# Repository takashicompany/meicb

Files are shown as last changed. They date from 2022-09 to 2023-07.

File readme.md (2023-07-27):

# MeiCB

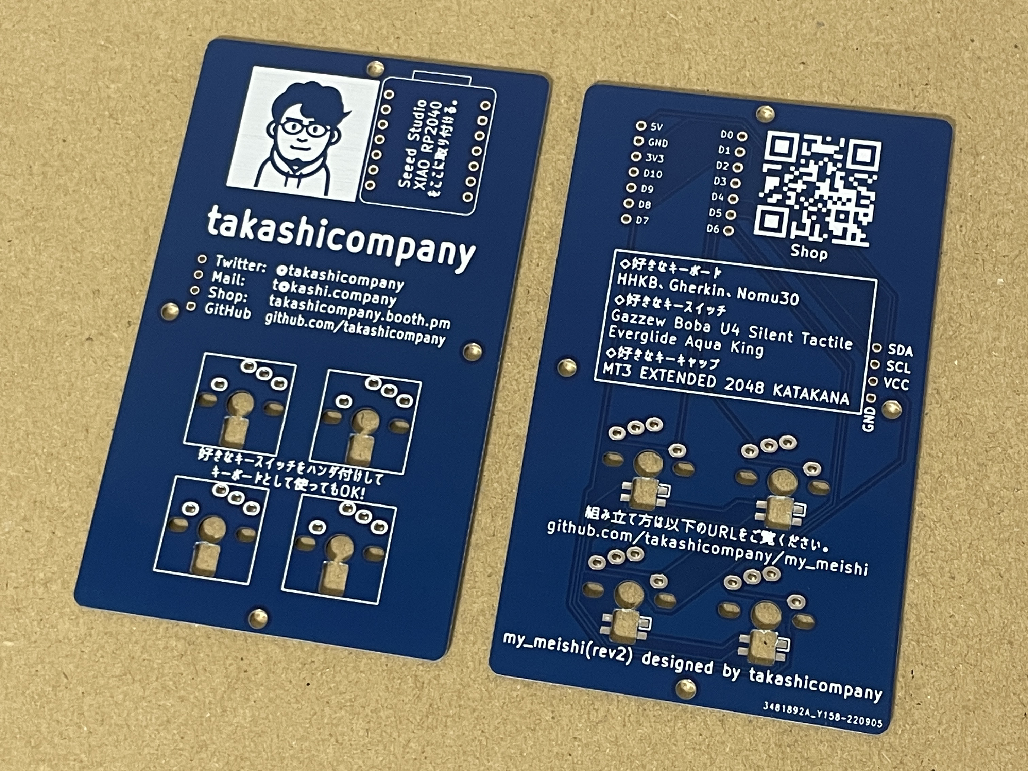
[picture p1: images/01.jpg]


MeiCB(メイシービー)は名刺サイズのキーボード基板です。  
名刺として使えますし、キースイッチやMCUを搭載することで簡易的なマクロパッドとしても利用できます。  
Kicadデーターを公開予定ですので、ご自身のプロフィールやアイコン画像を載せたMeiCBをつくることも可能です。  

(my_meishiから名前を変更しました。)

## 機能の対応状況

### Rev2(my_meishi)

一部の機能は、まだファームウェアの調査中だったり、基板側に拡張が必要なケースがあります。

|機能|対応|詳細|
|:--|:--|:--|
|OLED|？|現在調査中。|
|LED|✗|基板側で追加の実装が必要になる想定。|
|VIA|？|現在調査中。|

## 組み立てに必要な部品

|部品名|個数|備考|
|:--|:--|:--|
|[XIAO RP2040](https://akizukidenshi.com/catalog/g/gM-17044/)|1||
|キースイッチ|4個|取り付けは[Cherry MX互換キースイッチ](https://shop.yushakobo.jp/collections/all-switches/cherry-mx-%E4%BA%92%E6%8F%9B-%E3%82%B9%E3%82%A4%E3%83%83%E3%83%81)と[Kailh Choc v1互換キースイッチ](https://shop.yushakobo.jp/collections/all-switches/kailh-choc-v1%E3%82%B9%E3%82%A4%E3%83%83%E3%83%81)に対応|
|キーキャップ|4個||
|[ゴム足シール](https://shop.yushakobo.jp/collections/all-keyboard-parts/products/a0800ur-01-6)|4個||

## 組み立て方

### 1. 基板の表側にXIAO RP2040を取り付ける

基板の表側右上の箇所にXIAO RP2040を取り付けます。  
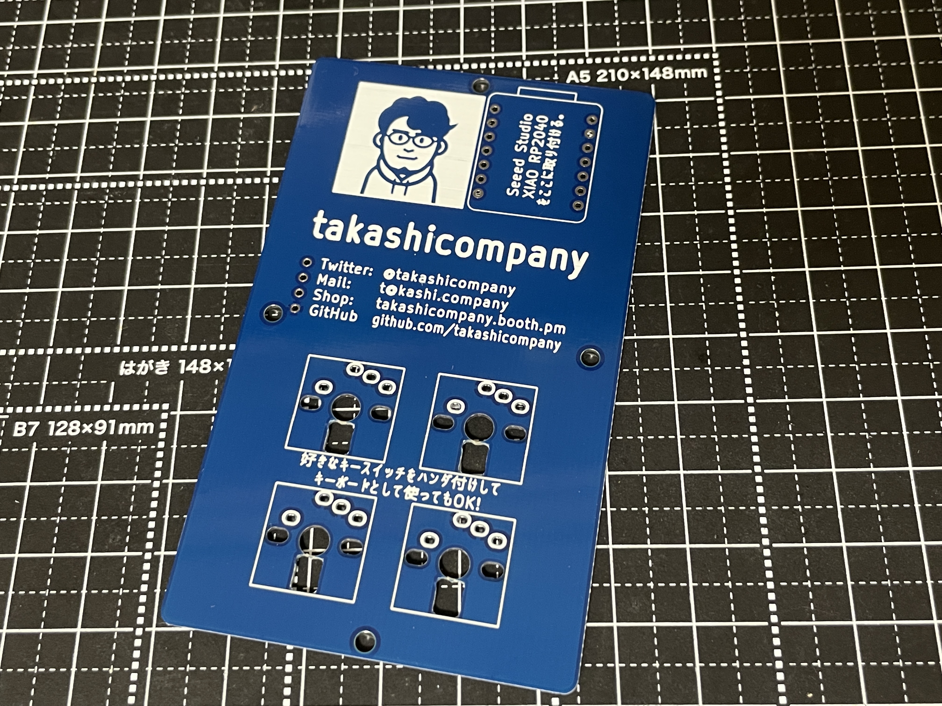
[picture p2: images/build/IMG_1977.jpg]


XIAO RP2040とピンをはんだ付けします。  
ピンの足がXIAO RP2040の平らな面側に来るようにピンを差しハンダ付けを行います。  
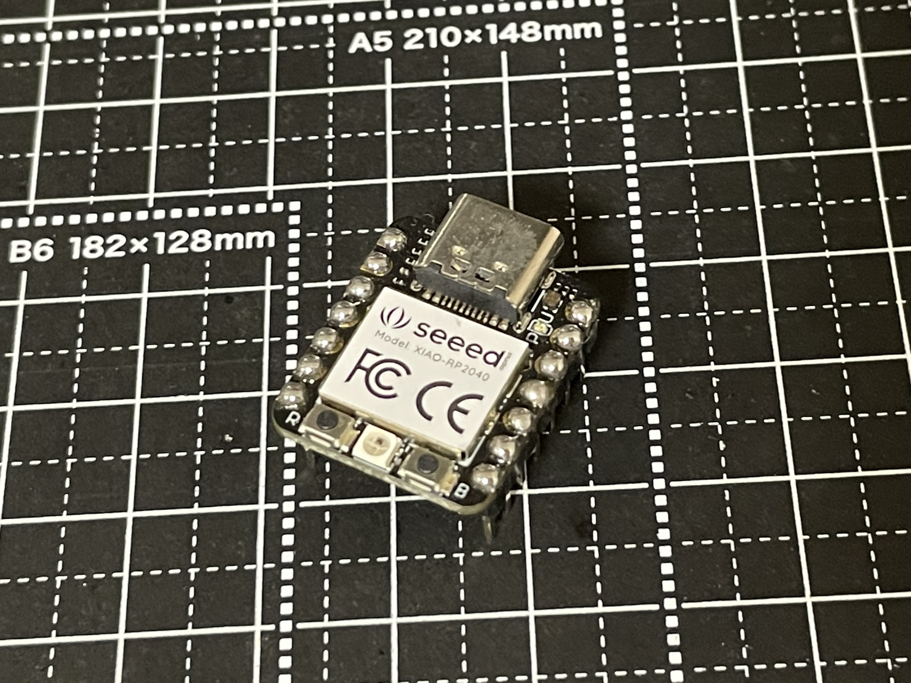
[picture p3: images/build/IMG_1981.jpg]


XIAO RP2040をMeiCB基板に差します。  
USBの口が外側を向くようにしてください。  
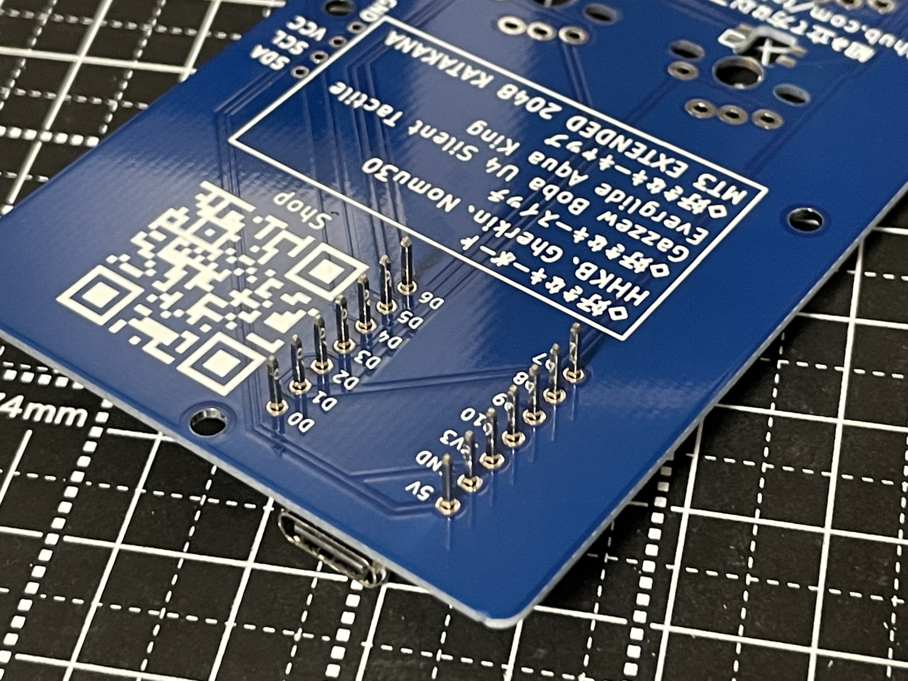
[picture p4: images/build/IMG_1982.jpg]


表面から見たときに、このようになっていれば問題ありません。  
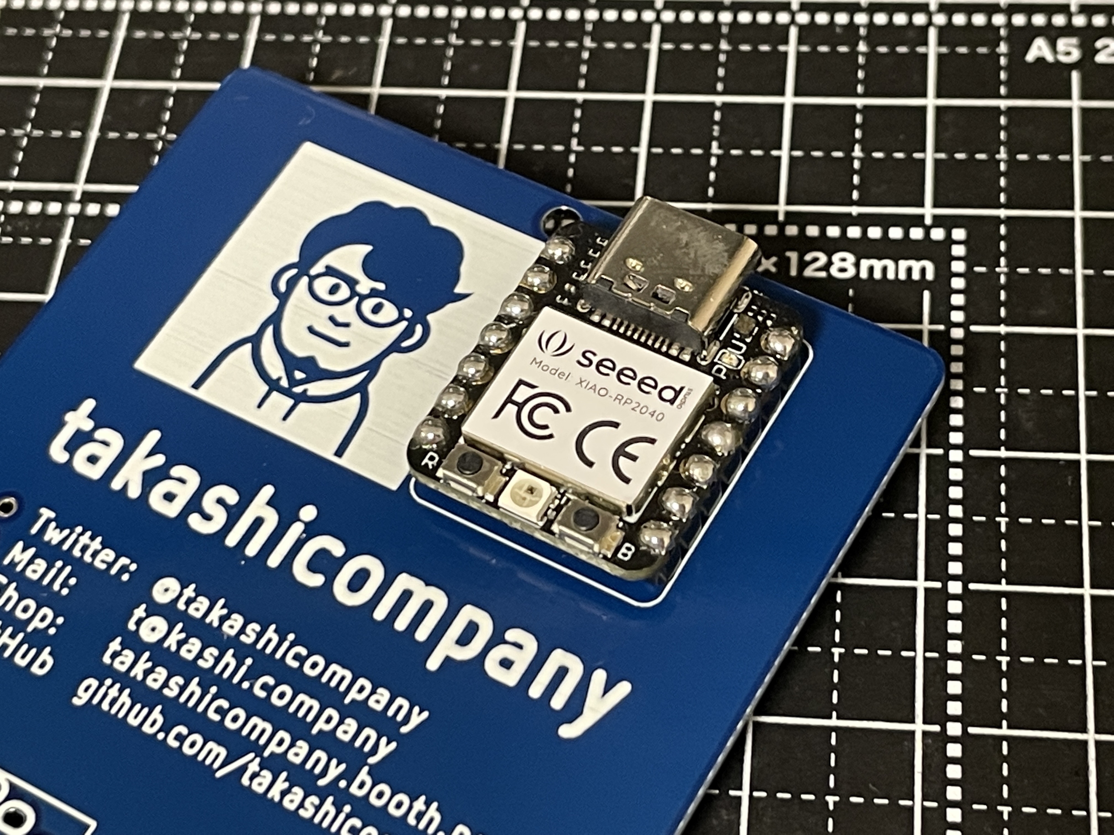
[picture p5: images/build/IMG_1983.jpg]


基板とピンをハンダ付けする前にピンをニッパーなどで短く切っておくとハンダ付けがしやすくなり且つ仕上がりが綺麗になります。  
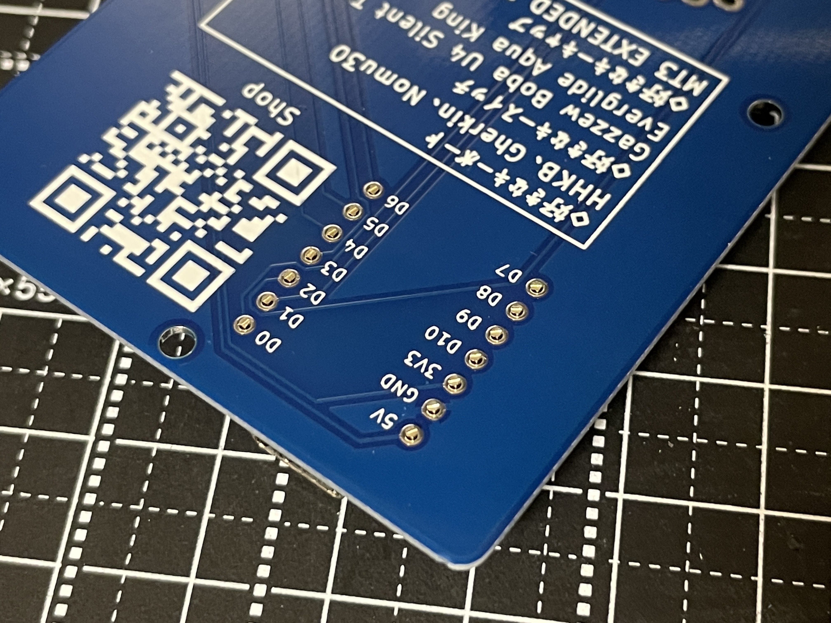
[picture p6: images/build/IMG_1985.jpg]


全てのピンをハンダ付けしたら完了です。  
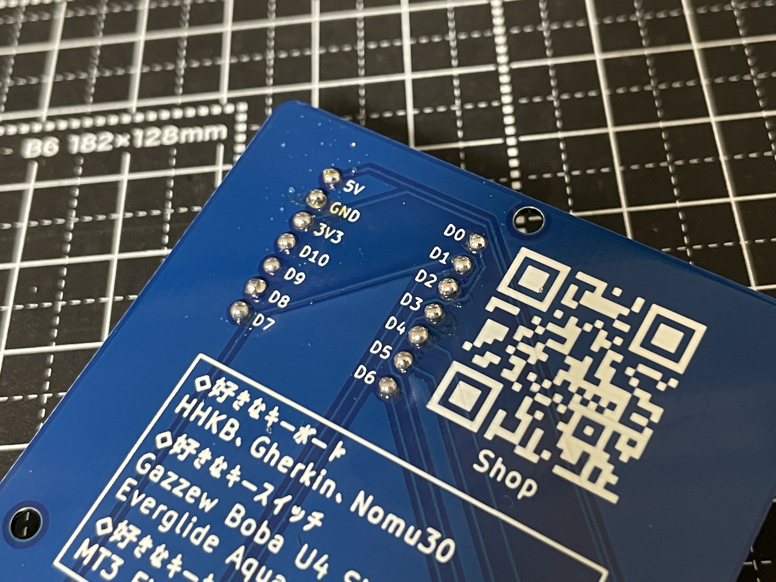
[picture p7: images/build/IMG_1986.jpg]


### 2. キースイッチを取り付ける

キースイッチを取り付けます。  
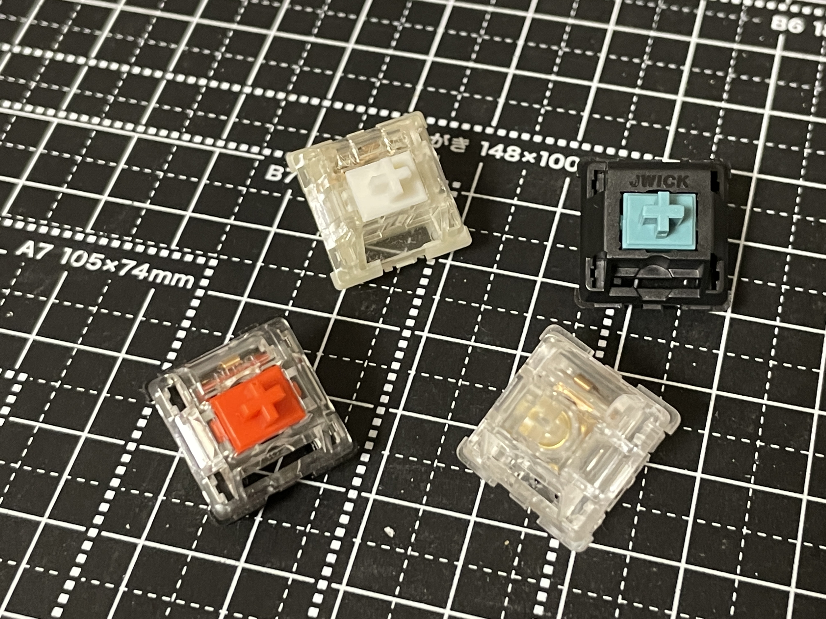
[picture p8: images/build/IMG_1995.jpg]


キースイッチをMeiCB基板に配置します。  
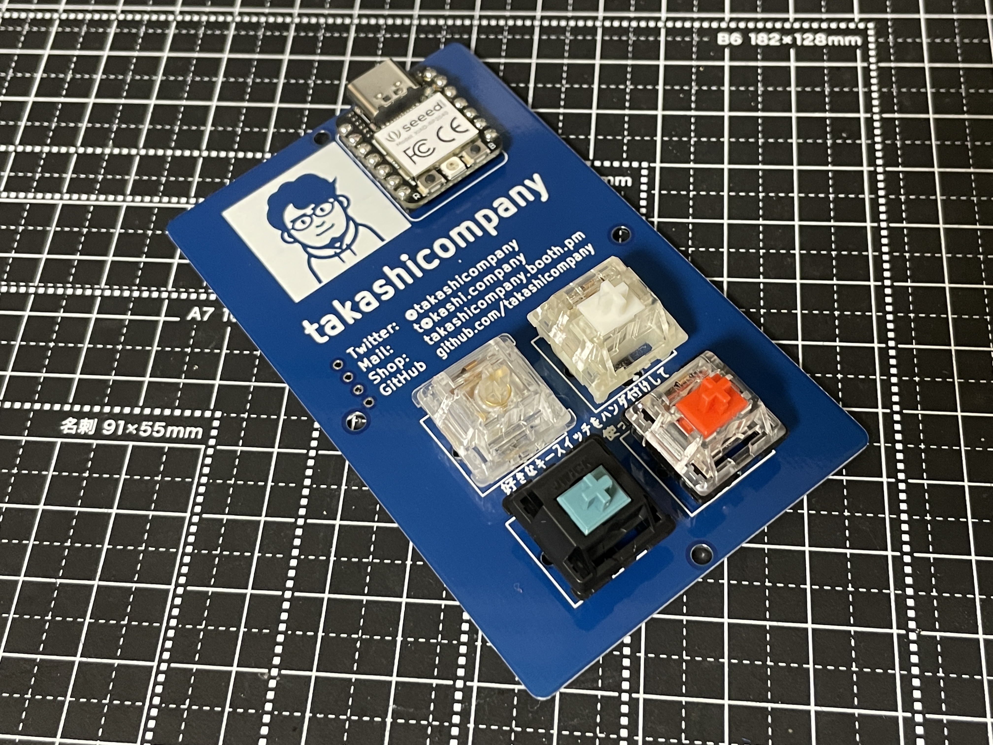
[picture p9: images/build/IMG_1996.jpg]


キースイッチをマスキングテープなどで固定すると、以降の作業をスムーズに進められます。  
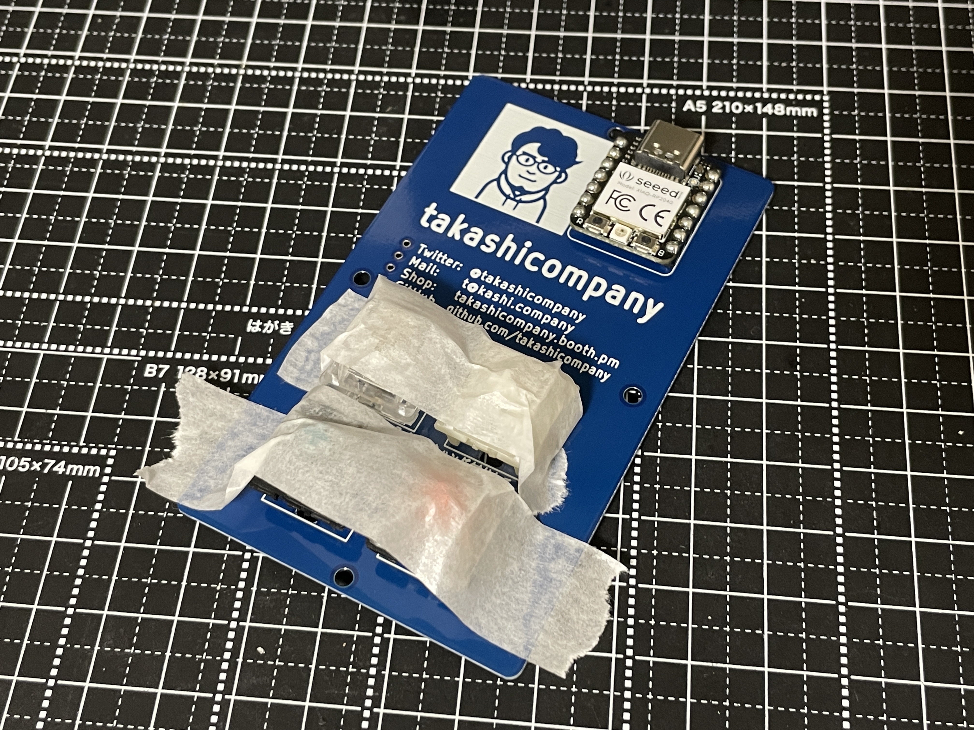
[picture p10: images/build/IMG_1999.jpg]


MeiCB基板を裏返したときに、キースイッチの足が出ていることを確認します。  
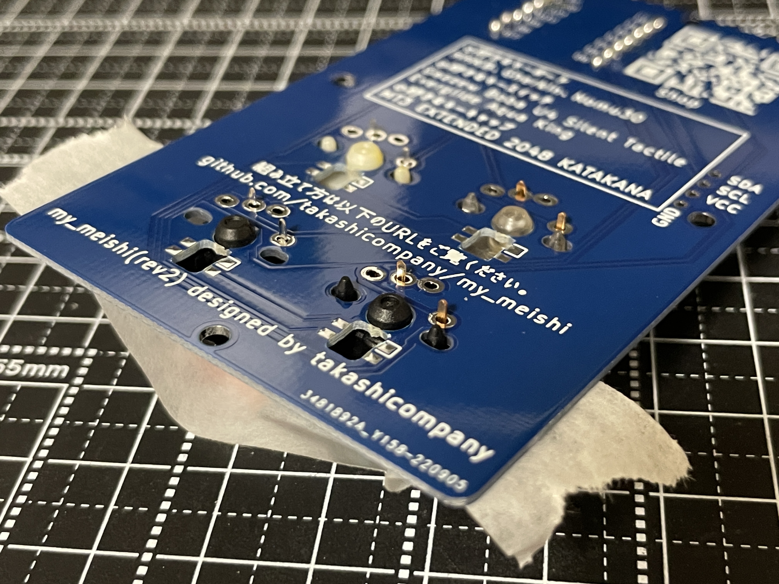
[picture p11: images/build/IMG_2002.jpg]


MeiCB基板とキースイッチをハンダ付けします。  
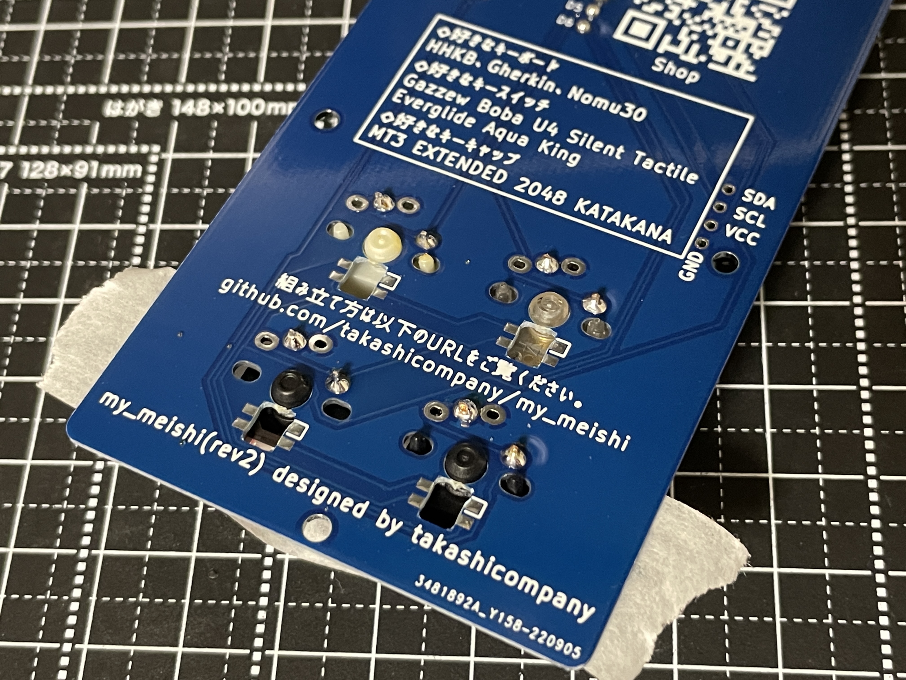
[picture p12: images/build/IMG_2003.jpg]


キーキャップを取り付けます。  
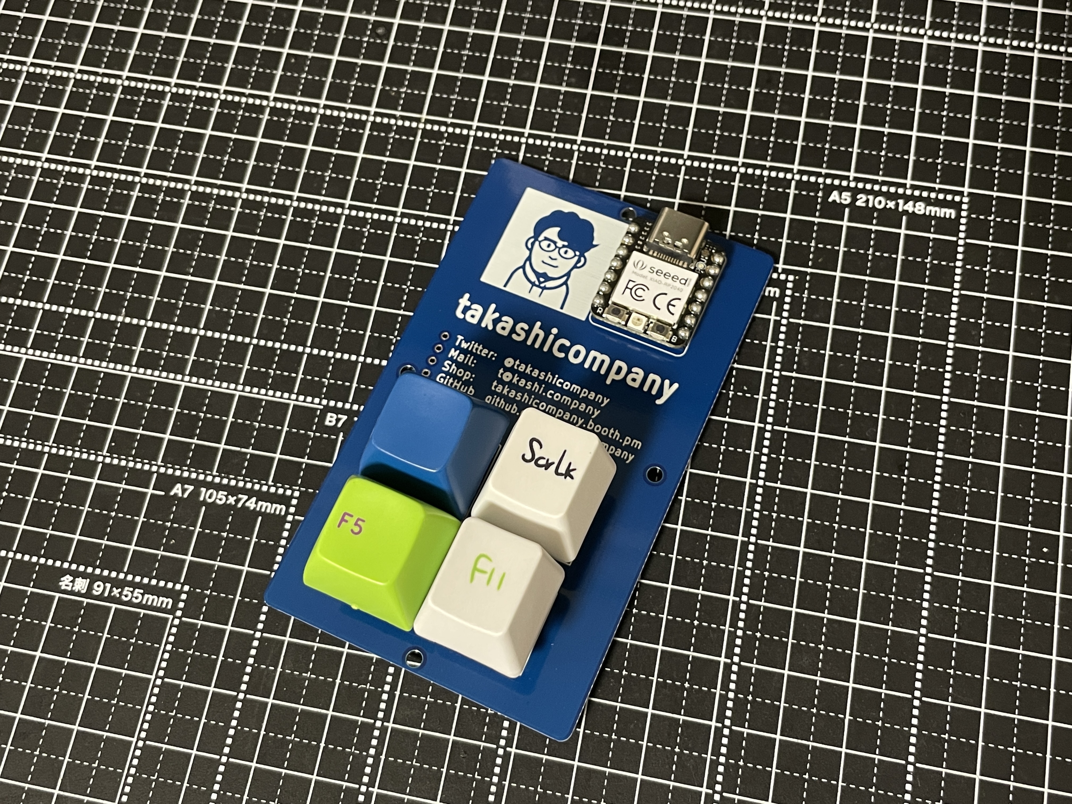
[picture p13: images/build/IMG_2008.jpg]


### 3. ファームウェアの書き込み

XIAO RP2040上のUSB口の反対側にある、Bと書かれたボタンを押しながらUSBを繋ぐとファームウェア書き込み状態にできます。

ファームウェアは[こちら](https://github.com/takashicompany/meicb/tree/master/firmware)にございます。

RPI-RP2と書かれたドライブに.uf2をドロップすると、書き込まれます。

ソースコードは[こちら](https://github.com/takashicompany/qmk_firmware/tree/meicb/v1/keyboards/takashicompany/meicb)です。



Remap等への対応は後日予定しております。

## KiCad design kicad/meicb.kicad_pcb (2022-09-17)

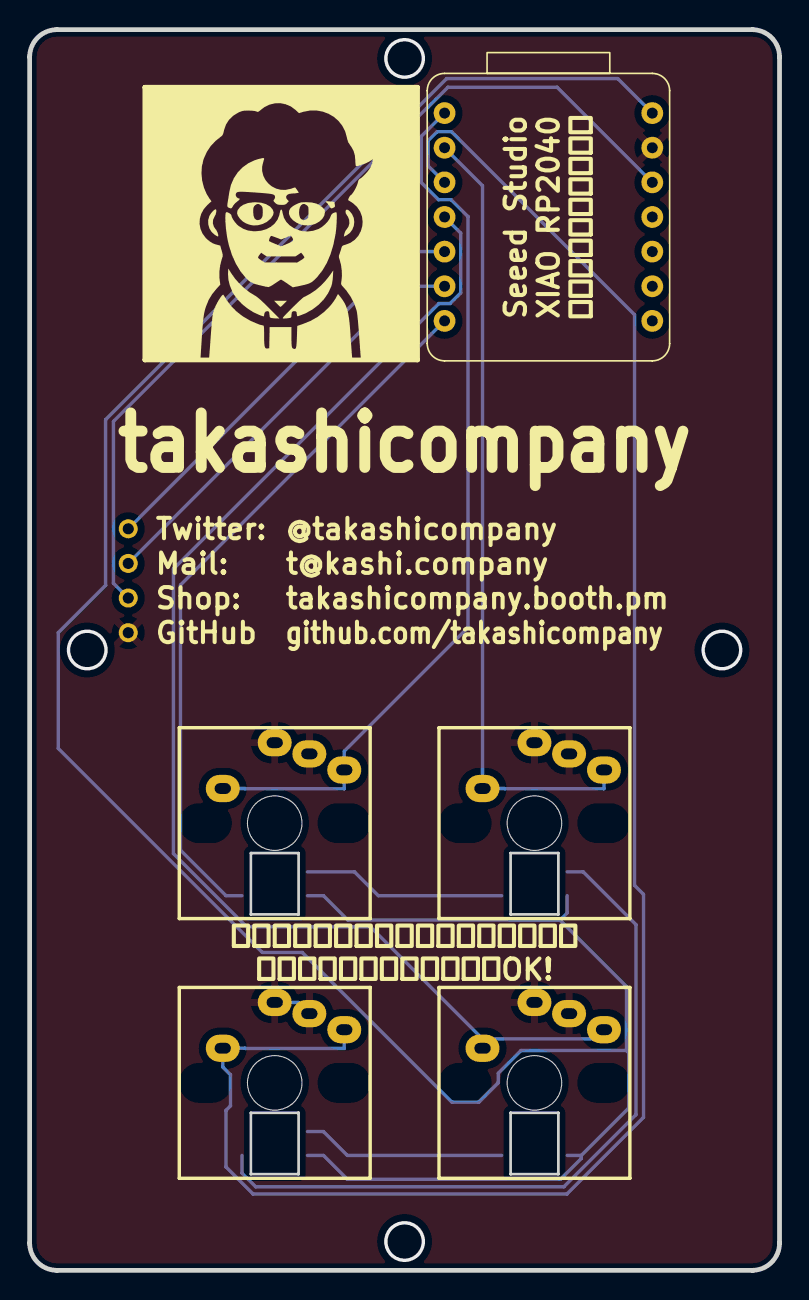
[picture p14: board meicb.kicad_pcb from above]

Board: 2 copper layers, 55.0 x 91.0 mm, 11 parts (0 on the bottom side), 13 nets.

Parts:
Icon: LOGO; icon
LED1, LED2, LED3, LED4: SK6812MINI-E; SK6812MINI_bg
M1: XIAO-RP2040; XIAO-RP2040-inside-only
OL1: OLED; OLED_v2
SW1, SW2, SW3, SW4: SW_Push; CherryMX-MidHeight-Choc_TH_Biased

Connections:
+3V3: M1.12 (3V3), OL1.3 (VCC)
+5V: LED1.1 (VDD), LED2.1 (VDD), LED3.1 (VDD), LED4.1 (VDD), M1.14 (5V)
GND: LED1.3 (VSS), LED2.3 (VSS), LED3.3 (VSS), LED4.3 (VSS), M1.13 (GND), OL1.4 (GND), SW1.2, SW2.2, SW3.2, SW4.2
unnamed: LED1.2 (DOUT), LED2.4 (DIN)
unnamed: LED2.2 (DOUT), LED3.4 (DIN)
unnamed: LED3.2 (DOUT), LED4.4 (DIN)
SCL: M1.6 (D5), OL1.2 (SCL)
SDA: M1.5 (D4), OL1.1 (SDA)
SW1_IN: M1.1 (D0), SW1.1
SW2_IN: M1.2 (D1), SW2.1
SW3_IN: M1.3 (D2), SW3.1
SW4_IN: M1.4 (D3), SW4.1
led: LED1.4 (DIN), M1.7 (D6)

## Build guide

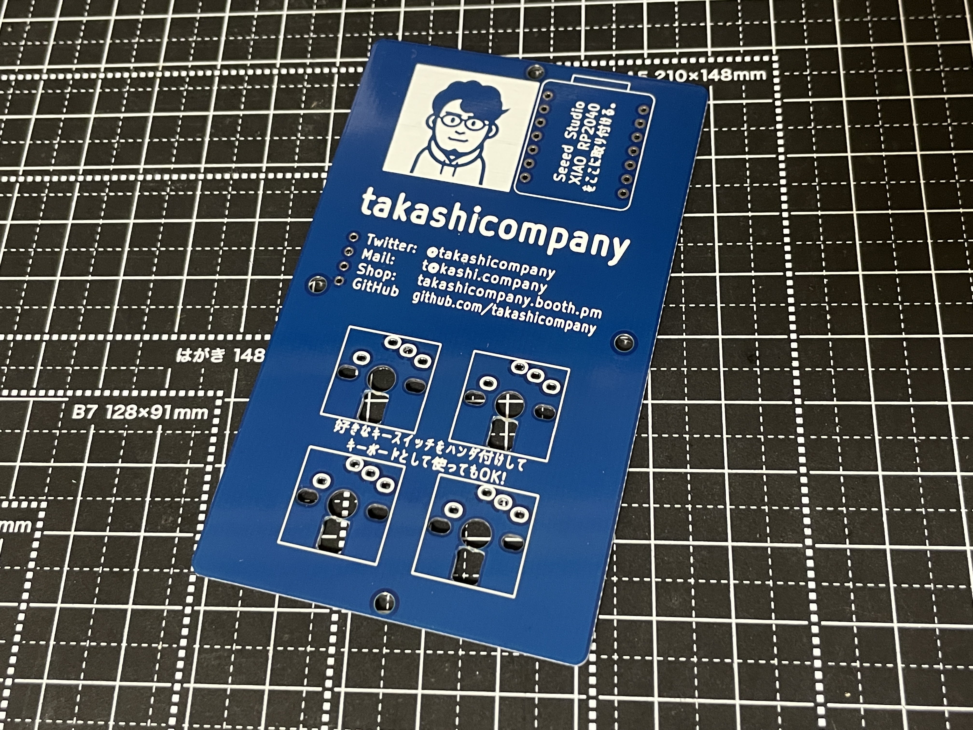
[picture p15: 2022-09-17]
images/build/IMG_1976.jpg

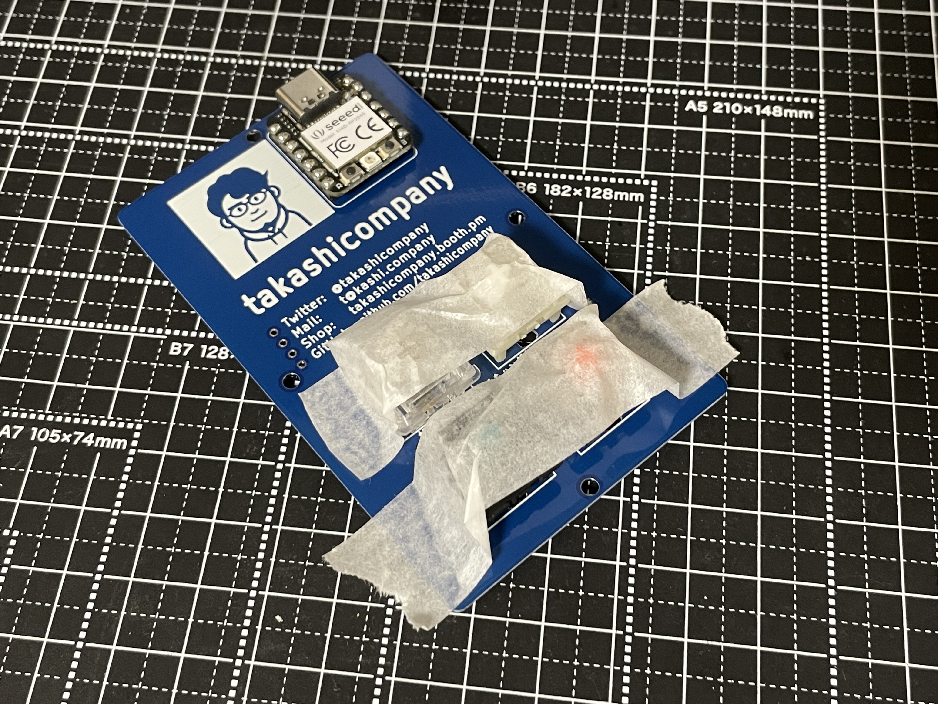
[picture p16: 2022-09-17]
images/build/IMG_1997.jpg

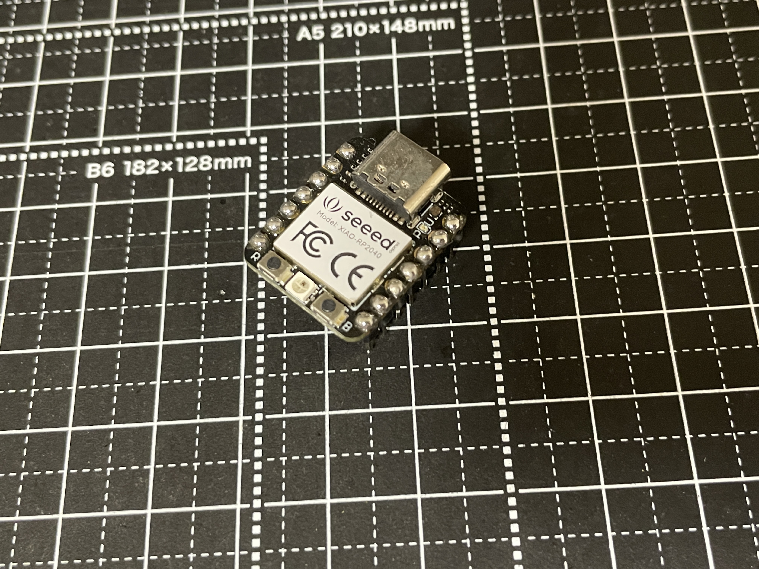
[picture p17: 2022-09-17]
images/build/IMG_1978.jpg

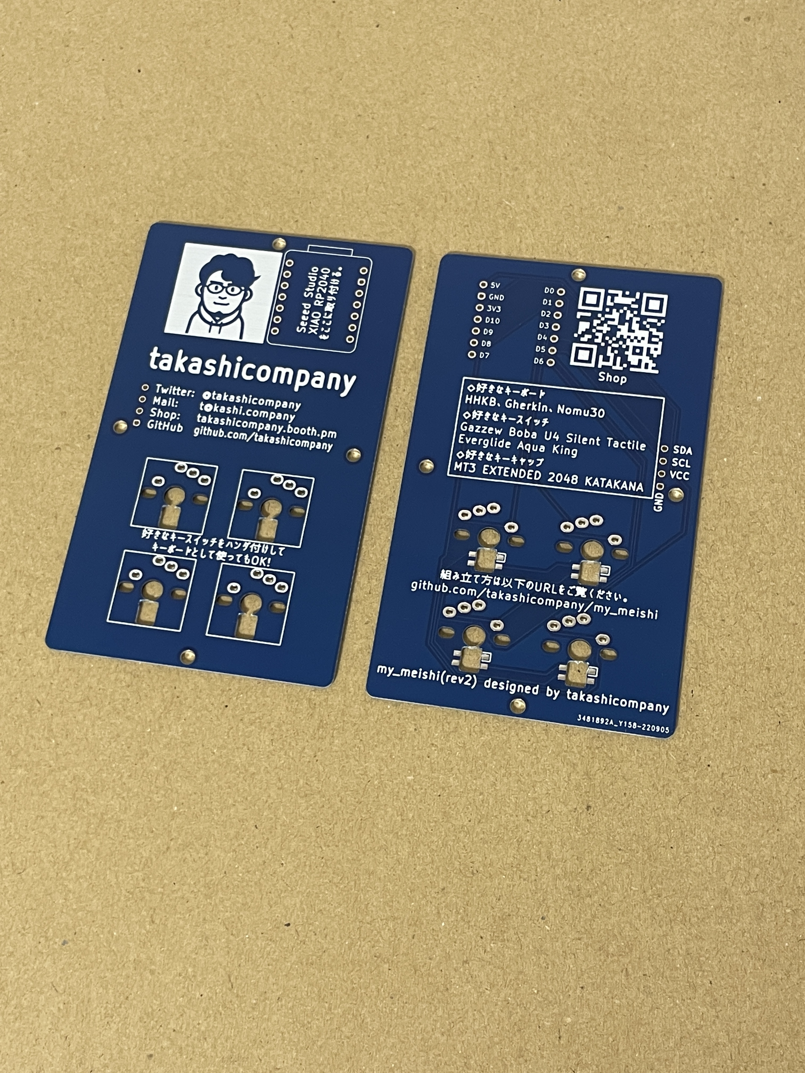
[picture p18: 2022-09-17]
images/build/IMG_1973.jpg

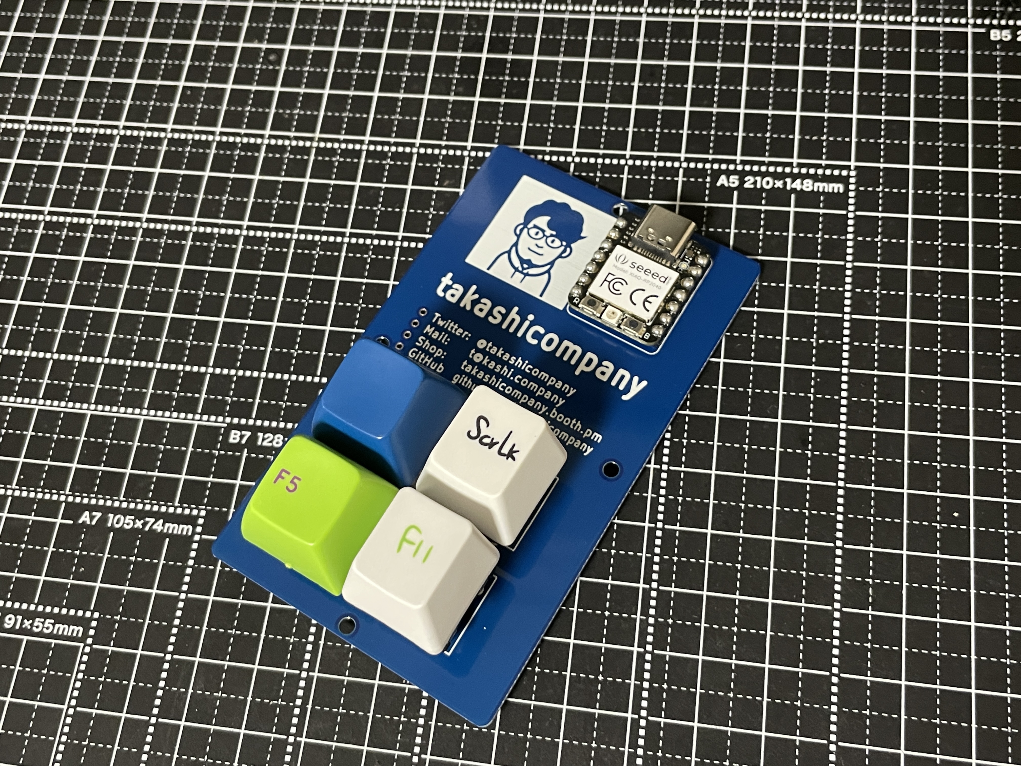
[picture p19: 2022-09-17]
images/build/IMG_2005.jpg

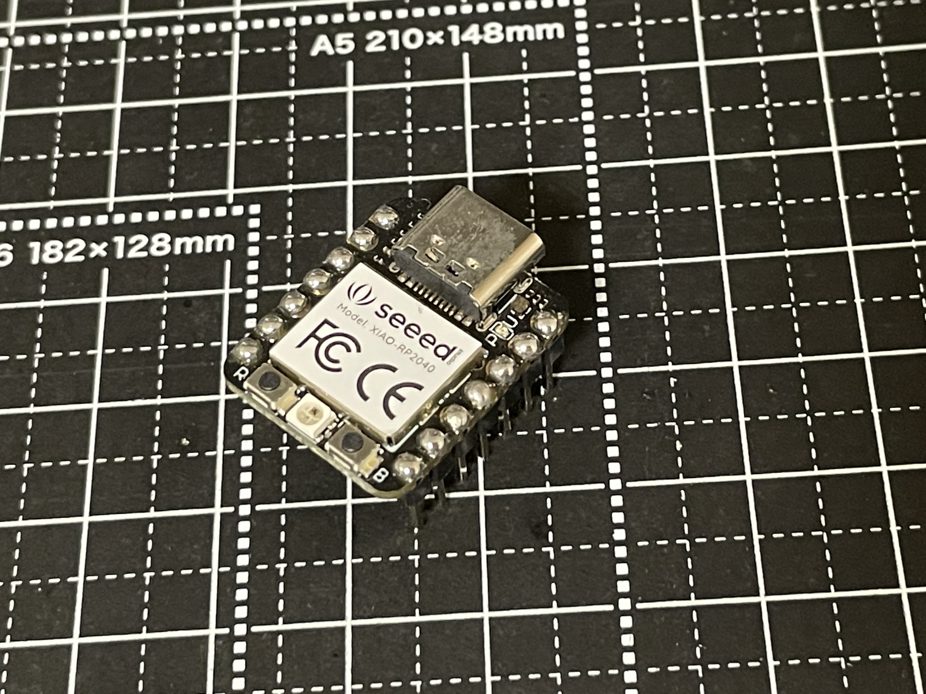
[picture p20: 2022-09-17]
images/build/IMG_1980.jpg

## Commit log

2022-09-17 DS Store消す
2022-09-17 画像を修正
2022-09-17 説明を追加
2022-09-17 Kicadを追加
    [my_meishi.kicad_pcb]
2022-09-18 ファームウェア
